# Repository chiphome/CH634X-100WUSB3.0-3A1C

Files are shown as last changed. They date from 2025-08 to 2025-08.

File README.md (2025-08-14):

# CH634X-100WUSB3.0-3A1C
CH634X芯片做的100W快充 + USB3.0高速传输（3A1C）PD HUB

bcbccf7359b1692e641148ebdd1c60ad

在日常开发中，USB HUB几乎是必不可少的工具，最近刚好需要一个HUB，作为一个电子工程师，我决定自己动手，设计并打造了一款自己的HUB，基于这个过程，顺便温习一下USB、PD的一些知识，如果大家有兴趣，咱们可以一起学习。

说一下我的情况，我的电脑只有2个Type-C口，所以设计的HUB必须支持快充，C口转A口最好有3个，额外再多一个C口更好。

ce3a1c8411e7a496146c697b6e25c82e

网上找了一圈，最终选定了沁恒微的CH634X这颗芯片做了一款HUB，已经打样测试完，现在决定全部资料开源给大家进行复刻。

🔧 项目简介：

一款为开发者量身定做的 USB HUB，整个USB HUB项目包含以下接口配置：

1、上行 Type-C 口：接入电脑主机，承担数据传输与充电功能

2、独立供电 Type-C 口：支持最大100W PD快充输入（20V/5A）

3、1个USB-C下行接口：连接USB-C设备实现高速通信

4、3个 USB-A下行接口：完美兼容鼠标、键盘、U盘、调试器等外设

所有的接口，都做了电源管理，安全稳定，支持边充边用、盲插盲用。

为什么选 CH634X？

CH634X芯片是一款带PD功能的高性能 USB3.0 控制芯片，主要性能特点：

1、单芯片集成4口USB3.2 Gen1(5Gbps) HUB和Type-C PD功能

2、原生支持Type-C电源100W快充，支持PDHUB和拓展坞

3、内置两组Type-C双通道 USB3.0 PHY和双PD PHY，原生支持Type-C正反插自适应

4、具有独立的SS HUB控制器和USB2.0 HUB控制器

5、支持 Type-C 上下行口热插拔识别与角色切换，便于2个主机管理多个设备

6、集成了3.3V的LDO调压器和1.2V的DC-DC降压器，支持外部5V电源供电，外围精简

7、支持通过I/O引脚配置独立或整体控制、供电模式等功能

8、封装小巧，适合各种紧凑布局

b80117e6-9387-49b2-9819-d8cde15263a5

最关键的是：国产、自研、文档齐全，易于上手！

项目架构图&PCB预览

接口配置：

Snipaste_2025-08-06_22-08-11

原理图，具体原理分析下一篇文章介绍：

SCH_CH634X-PD-R0-1v1A_1-CH634X-PD-R0-1v1A_2025-08-07

PCB用立创EDA制作，采用4层板设计，专门优化了电源走线与高速信号完整性。

Snipaste_2025-08-07_21-01-03

PCB 3D

Snipaste_2025-08-07_21-09-59

外壳文件，外壳提供STP格式，大家可以3D打印，外壳还有很多优化空间。

b57ac5e0cf575fdb12473ac2b80c06bb

提供交互式BOM清单，以及excel版本的BOM，PCB工程中就已经包含了标准化元器件信息，99%的器件均可在立创商城直接找到。

Snipaste_2025-08-07_21-13-05

PCB为4层板，USB涉及到的高速信号需要走差分信号，并进行阻抗管控，层压结构采用嘉立创 JLC04161H-3313，阻抗管控，免费的±20%。

51ed610ea196499222fcb1e0d58c3bfd

⚡ 实测效果：PD快充 + 高速传输一个不落！

💻 插入Windows电脑测试，PD握手成功，支持 20V/5A 快充

🚀 同时连接U盘/调试器/外设，USB3.0速度可达400MB/s+

🔌 使用小米/Anker/绿联等主流PD充电器，均握手无压力

📱 给手机、笔记本充电 + 外设传输，边用边充非常流畅

Windows系统 HP电脑电量10%以下充电功率能达到95W。

15295ae347ca00ae9c601f69119ef222

MAC系统 18款macbook pro电量10%以下充电功率能达到58W，新款MAC支持到100W应该没问题。

97588eadf752a5da45506af6988280b0

Type-A口高速传输测试，固态硬盘采用闪迪 500GB NVMe固态硬盘，Type-C接口，最高速度1050MB/s，远高于USB3.2 Gen1（5Gbps）的速度，所以用这个SSD测试就能测试出USB口的最大传输速度，实际不同的电脑测试出来的结果会有一些差别,本次测试电脑型号为OptiPlex 7080。

测试软件用CrystalDiskMark8_0_6Aoi，测试结果如下：

固态硬盘直连电脑测试，读828MB/s，写833MB/s：

5fb19ae172b27eedad27e1608d564398

经过Hub后A口测试，读448MB/s，写446MB/s：

9f602b78e34173029b9afdeb7f088027

经过Hub后C口测试，读448MB/s，写446MB/s：

8f730b265e7b2e1171c0086d2a173663

完全开源，欢迎大家 Fork & DIY

我会将整个项目的内容发布到立创开源硬件平台，包括：

✅ 原理图设计+4层PCB（立创EDA）

✅ 3D外壳模型（塑料外壳+铝合金可选）

✅ BOM物料清单

✅ 原理分析

大家搜“100W快充+USB3.0（3A+1C）高速传输 PD HUB”就可以找到项目，可以很方便的进行复刻，相关外壳3D，BOM,原理图PCB等文件都可以从这里下载。
https://oshwhub.com/karaxiaoyu/ch634x-pd-r0-1v1_20250808

2a50b48fd187012e1b65d90dd20057a

为什么我要开源这个项目？

与其等，不如自己做；与其藏，不如分享。

这正是这个项目的初衷 —— 用开源推动国产芯片更广泛应用，也让更多电子爱好者可以低成本DIY一个实用的桌面工具。

e311dd5fef292941c57d9ddc25b08a0e

读到这里的都是忠实的粉丝了，大家一键三连点赞👍支持下国产芯片和开源项目。

留言交流🗨️提出想法、建议、改进点。

分享扩散 🚀 让更多朋友加入到国产芯片生态中！

你觉得这样的HUB实用吗？文章下面留言告诉我，我将抽1位幸运粉丝送出一个实物样品！🎁

因为篇幅问题，本篇我们先把项目开源出来，下一篇我们重点分析下整个板子的工作原理，芯片大概是怎么工作的，PD是怎么握手的，再重点分析。

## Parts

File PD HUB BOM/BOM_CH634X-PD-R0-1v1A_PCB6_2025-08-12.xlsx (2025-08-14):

No. | Quantity | Comment | Designator | Footprint | Value | Manufacturer Part | Manufacturer | Supplier Part | Supplier
1 | 2 | 20pF | C1,C2 | C0402 | 20pF | 0402CG200J500NT | FH(风华) | C1554 | LCSC
2 | 9 | 1uF | C3,C8,C9,C17,C18,C19,C23,C39,C40 | C0402 | 1uF | 0402X105K160NT | FH(风华) | C167339 | LCSC
3 | 3 | 10uF | C4,C6,C45 | C0603 | 10uF | 0603X106M250NT | FH(风华) | C479655 | LCSC
4 | 22 | 100nF | C5,C7,C10,C11,C20,C21,C25,C26,C27,C28,C31,C32,C33,C34,C35,C36,C37,C38,C41,C42,C43,C44 | C0402 | 100nF | 0402B104K500NT | FH(风华) | C110251 | LCSC
5 | 3 | 22uF | C12,C14,C15 | C0805 | 22uF | 0805X226M250NT | FH(风华) | C129303 | LCSC
6 | 1 | 220uF | C16 | CAP-TH_BD6.3-P2.50-D0.6-FD-1 | 220uF | KS227M016E07RR0VH2FP0 | CX(承兴) | C43340 | LCSC
7 | 1 | 47uF | C22 | C1206 | 47uF | 1206X476M160NT | FH(风华) | C172351 | LCSC
8 | 3 | 100uF | C24,C29,C30 | CAP-TH_BD6.3-P2.60-D0.6-FD-1 | 100uF | CD288H1VM101E70T | 创慧电子 | C25503879 | LCSC
9 | 2 | DS34W | D1,D2 | SOD-123FL_L2.7-W1.8-LS3.8-RD |  | DS34W | 晶导微电子 | C123903 | LCSC
10 | 1 | 2.2uH | L1 | IND-SMD_L3.0-W3.0_FNR30XXS | 2.2uH | SMNR4020-2.2UH | SXN(顺翔诺) | C135262 | LCSC
11 | 1 | 15uH | L2 | IND-SMD_L7.1-W6.6 | 15uH | SWPA6045S150MT | Sunlord(顺络) | C83374 | LCSC
12 | 1 | A-SP192DGHC-C01-4T | LED1 | LED0603-FD |  | A-SP192DGHC-C01-4T | Amicc(欧密格光电) | C19171301 | LCSC
13 | 1 | TYPE-C 24P QCHT | P1 | TYPE-C-SMD_TYPE-C-24P-QCHT |  | TYPE-C 24P QCHT | SHOU HAN(首韩) | C456013 | LCSC
14 | 3 | USB-301WD-ARY | P2,P3,P4 | USB-TH_XUNPU_USB-301WD-ARY |  | USB-301WD-ARY | XUNPU(讯普) | C2895025 | LCSC
15 | 1 | PC | P5 | CABLE-TYPEC1
16 | 1 | TYPE-C 16PIN 2MD(073) | P6 | USB-C-SMD_TYPE-C-6PIN-2MD-073 |  | TYPE-C 16PIN 2MD(073) | SHOU HAN(首韩) | C2765186 | LCSC
17 | 1 | PZ254V-11-03P | P7 | HDR-TH_3P-P2.54-V-M |  | PZ254V-11-03P | XFCN(兴飞) | C2937625 | LCSC
18 | 1 | PZ254V-11-05P | P8 | HDR-TH_5P-P2.54-V-M |  | PZ254V-11-05P | XFCN(兴飞) | C492404 | LCSC
19 | 2 | SED3080M | Q1,Q2 | DFN-8_L3.1-W3.0-P0.65-LS3.3-BL |  | SED3080M | SINO-IC(光宇睿芯) | C238667 | LCSC
20 | 3 | 10kΩ | R1,R2,R11 | R0402 | 10kΩ | RC0402FR-0710KL | YAGEO(国巨) | C60490 | LCSC
21 | 1 | 1kΩ | R3 | R0402 | 1kΩ | RC0402FR-071KL | YAGEO(国巨) | C106235 | LCSC
22 | 2 | 680kΩ | R4,R5 | R0402 | 680kΩ | RC0402FR-07680KL | YAGEO(国巨) | C163456 | LCSC
23 | 2 | 0Ω | R6,R18 | R0402 | 0Ω | RC0402FR-070RL | YAGEO(国巨) | C106231 | LCSC
24 | 1 | 5.1kΩ | R7 | R0402 | 5.1kΩ | RC0402FR-075K1L | YAGEO(国巨) | C105872 | LCSC
25 | 1 | 105kΩ | R8 | R0402 | 105kΩ | RC0402FR-07105KL | YAGEO(国巨) | C171671 | LCSC
26 | 1 | 20kΩ | R9 | R0402 | 20kΩ | RC0402FR-0720KL | YAGEO(国巨) | C93942 | LCSC
27 | 1 | 2kΩ | R10 | R0402 | 2kΩ | RC0402FR-072KL | YAGEO(国巨) | C60488 | LCSC
28 | 4 | 24kΩ | R14,R15,R16,R17 | R0402 | 24kΩ | RC0402FR-0724KL | YAGEO(国巨) | C138026 | LCSC
29 | 2 | Test-Point | TP1,TP2 | Test-Point-0.5mm
30 | 1 | CH634X | U1 | QFN-68_L8.0-W8.0-P0.40-TL-EP5.5 |  | CH634X | WCH(南京沁恒) | C48985831 | LCSC
31 | 1 | ETA2807FT2G | U2 | TSOT-23-6_L2.9-W1.6-P0.95-LS2.8-BL |  | ETA2807FT2G | ETA(钰泰) | C22362744 | LCSC
32 | 1 | CH211C | U3 | QFN16C_2X2 |  | CH211C | WCH(南京沁恒) |  | LCSC
33 | 4 | CH217K | U4,U5,U6,U7 | SOT-23-6_L2.9-W1.6-P0.95-LS2.8-BL |  | CH217K | WCH(南京沁恒) | C7462749 | LCSC
34 | 1 | 24MHz | X1 | CRYSTAL-SMD_4P-L3.2-W2.5-BL | 24MHz | X322524MSB4SI | YXC(扬兴晶振) | C15643 | LCSC

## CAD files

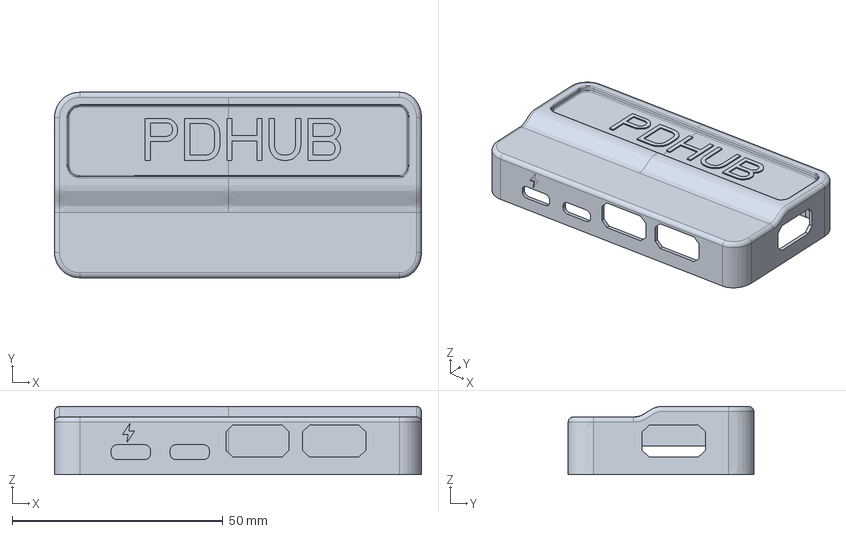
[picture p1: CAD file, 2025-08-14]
3D外壳/shangke.stp
87.0 x 44.0 x 16.2 mm

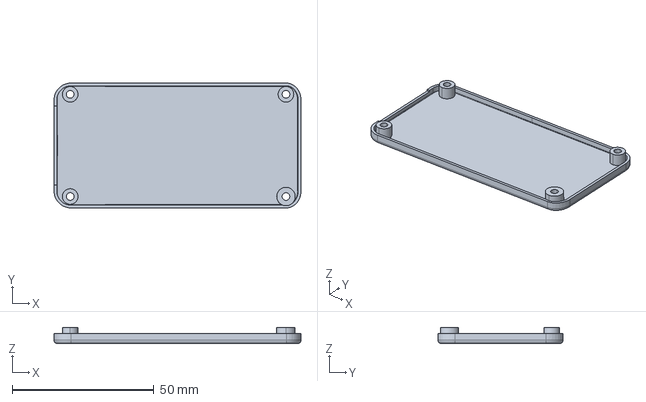
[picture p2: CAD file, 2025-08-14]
3D外壳/xiake.stp
87.0 x 44.0 x 5.73 mm
